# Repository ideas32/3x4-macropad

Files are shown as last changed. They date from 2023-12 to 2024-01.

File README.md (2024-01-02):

# 3x4 macropad
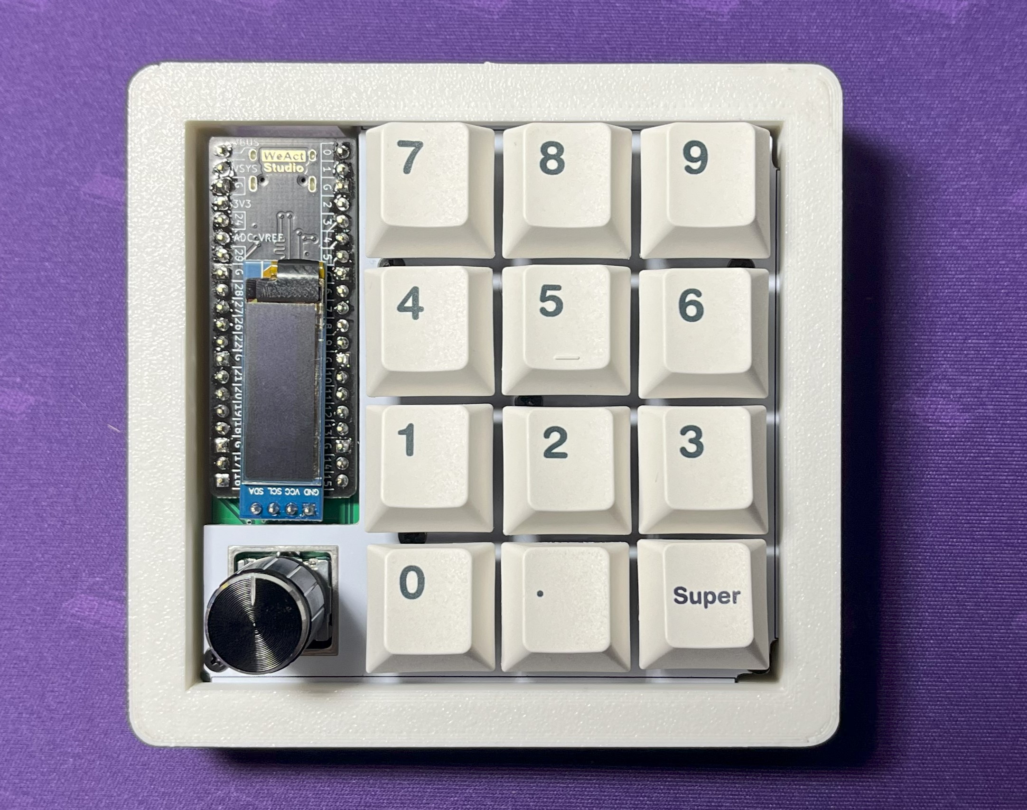
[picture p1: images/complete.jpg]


A 3x4 hotswap macropad with per-key rgb, rgb underglow, an oled, and an encoder. Uses the Weact Pi Pico as the microcontroller.
## Features:
- 3x4 array of south-facing MX switches
- hotswap (kailh sockets or equivilant)
- gasket mount
- support for a single 128x32 OLED placed above the microcontroller
- support for a single Alps EC11 rotary encoder
- support for addresable per-key rgb (SK6812 MINI-E) 
- support for addresable rgb underglow (WS2812b)
- through-hole and surface mount diode compatible
- uses a WeAct Studio Pi Pico as the microcontroller 
## Parts List
- 1x Weact Pi Pico
- 1x Alps EC11 encoder
- 12x Kailh or equivilant hotswap sockets
- 14x 1n4148 signal diodes (I prefer through-hole for ease of soldering, but surface mount is also supported)
- 16x M2x3mm screws, preferably with a thin head
- 6x M2x4mm female-female standoffs
- 12x MX-style switches
- 12x MX-style keycaps
- 1x Alps EC11 encoder knob
- 1x PCB, 1.6mm thick
- 1x Plate, 1.6mm thick (I recommend FR4)
- 1x 3d printed Case Top 
- 1x 3d printed Case Bottom 
- 1x 4-6mm thick sheet of foam to make gaskets OR gaskets around 4mm wide by 80mm long by 4-6mm high
- 12x SK6812 Mini-E LEDs (optional)
- 4x WS2812B LEDs (optional)
- 2x 4k7 resistors (only if using OLED)
- 1x SSD1306 128x32 OLED (optional)

Total cost excluding filament, switches, and keycaps when sourced from AliExpress and JLCPCB: ~$50
## Tools Required
- Screwdriver
- Soldering iron, solder, and basic soldering skills (SMD and THT)
- Flush cutters
- QMK source code and knowlege of how to build from source
- 3D printer and filament
# [Build Guide](Build%20Guide.md)

# Notes on the case:
- All filaments except PETG should be ok. I recommend staying away from PETG unless small holes turn out dimensionally accurate (which was not true in my case).
- Bottom case should be printed with transparent filament if using underglow
- Bottom case does require supports, top case does not
- Top case should be printed upside down
- Top case uses 4 M2 heatset inserts
- Assembled using 4x M2x3mm

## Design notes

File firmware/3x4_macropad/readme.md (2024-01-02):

# 3x4_macropad

3x4_macropad

A 3x4 macropad with encoder and 128x64 oled support. Uses the WeAct Studio RP2040 Core Board (WeAct Studio Pi Pico) as the microcontroller. 
* Keyboard Maintainer: [Kean Li](https://github.com/ideas32)
* Hardware Supported: WeAct RP2040 Coreboard (WeAct Pi Pico)
* Hardware Availability: *Links to where you can find this hardware*

Make example for this keyboard (after setting up your build environment):

    make 3x4_macropad:default

Flashing example for this keyboard:

    make 3x4_macropad:default:flash

See the [build environment setup](https://docs.qmk.fm/#/getting_started_build_tools) and the [make instructions](https://docs.qmk.fm/#/getting_started_make_guide) for more information. Brand new to QMK? Start with our [Complete Newbs Guide](https://docs.qmk.fm/#/newbs).

## Bootloader

Enter the bootloader in 3 ways:

* **Bootmagic reset**: Hold down the top-left key and plug in the keyboard
* **Physical reset button**: Press the button on the Pi Pico labeled "BOOTSEL" while plugging the keyboard in
* **Keycode in layout**: Press the key mapped to `QK_BOOT` if it is available

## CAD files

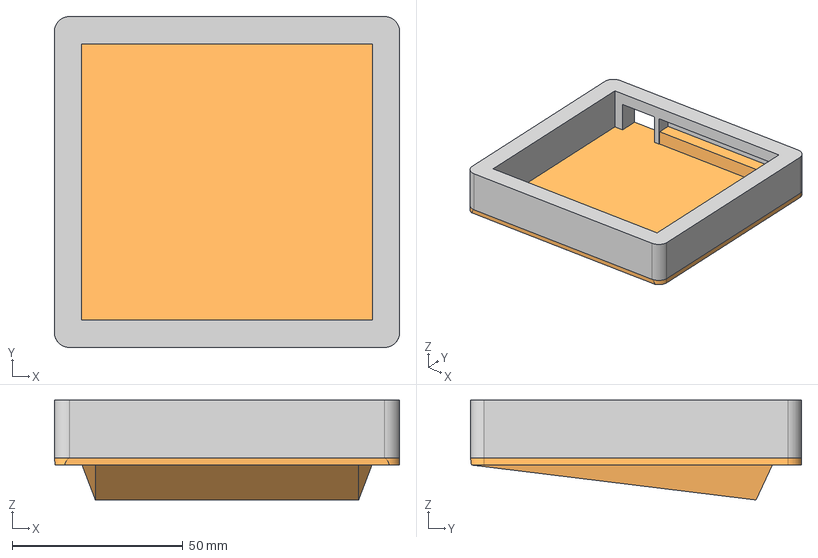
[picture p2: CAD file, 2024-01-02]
Case/Case.step
101.1 x 96.9 x 29.3 mm

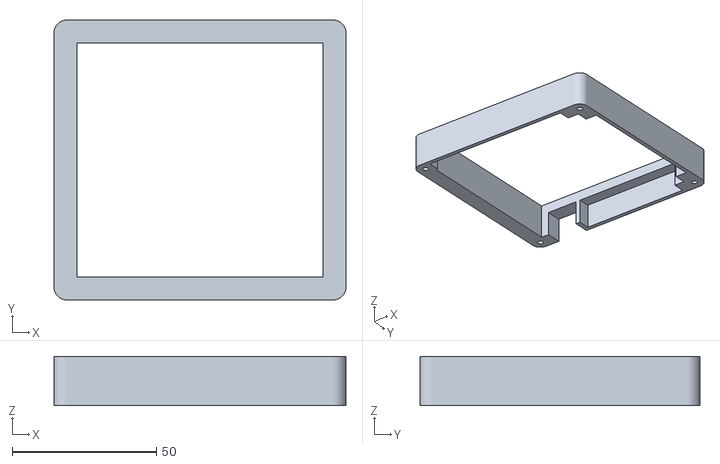
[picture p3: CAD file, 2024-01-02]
Case/Top Case.stl
101.1 x 96.9 x 17.0

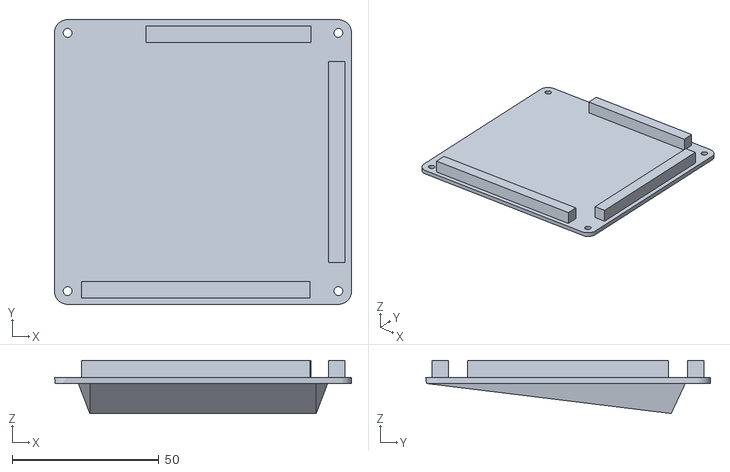
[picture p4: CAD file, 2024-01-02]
Case/Bottom Case.stl
101.1 x 96.9 x 18.1

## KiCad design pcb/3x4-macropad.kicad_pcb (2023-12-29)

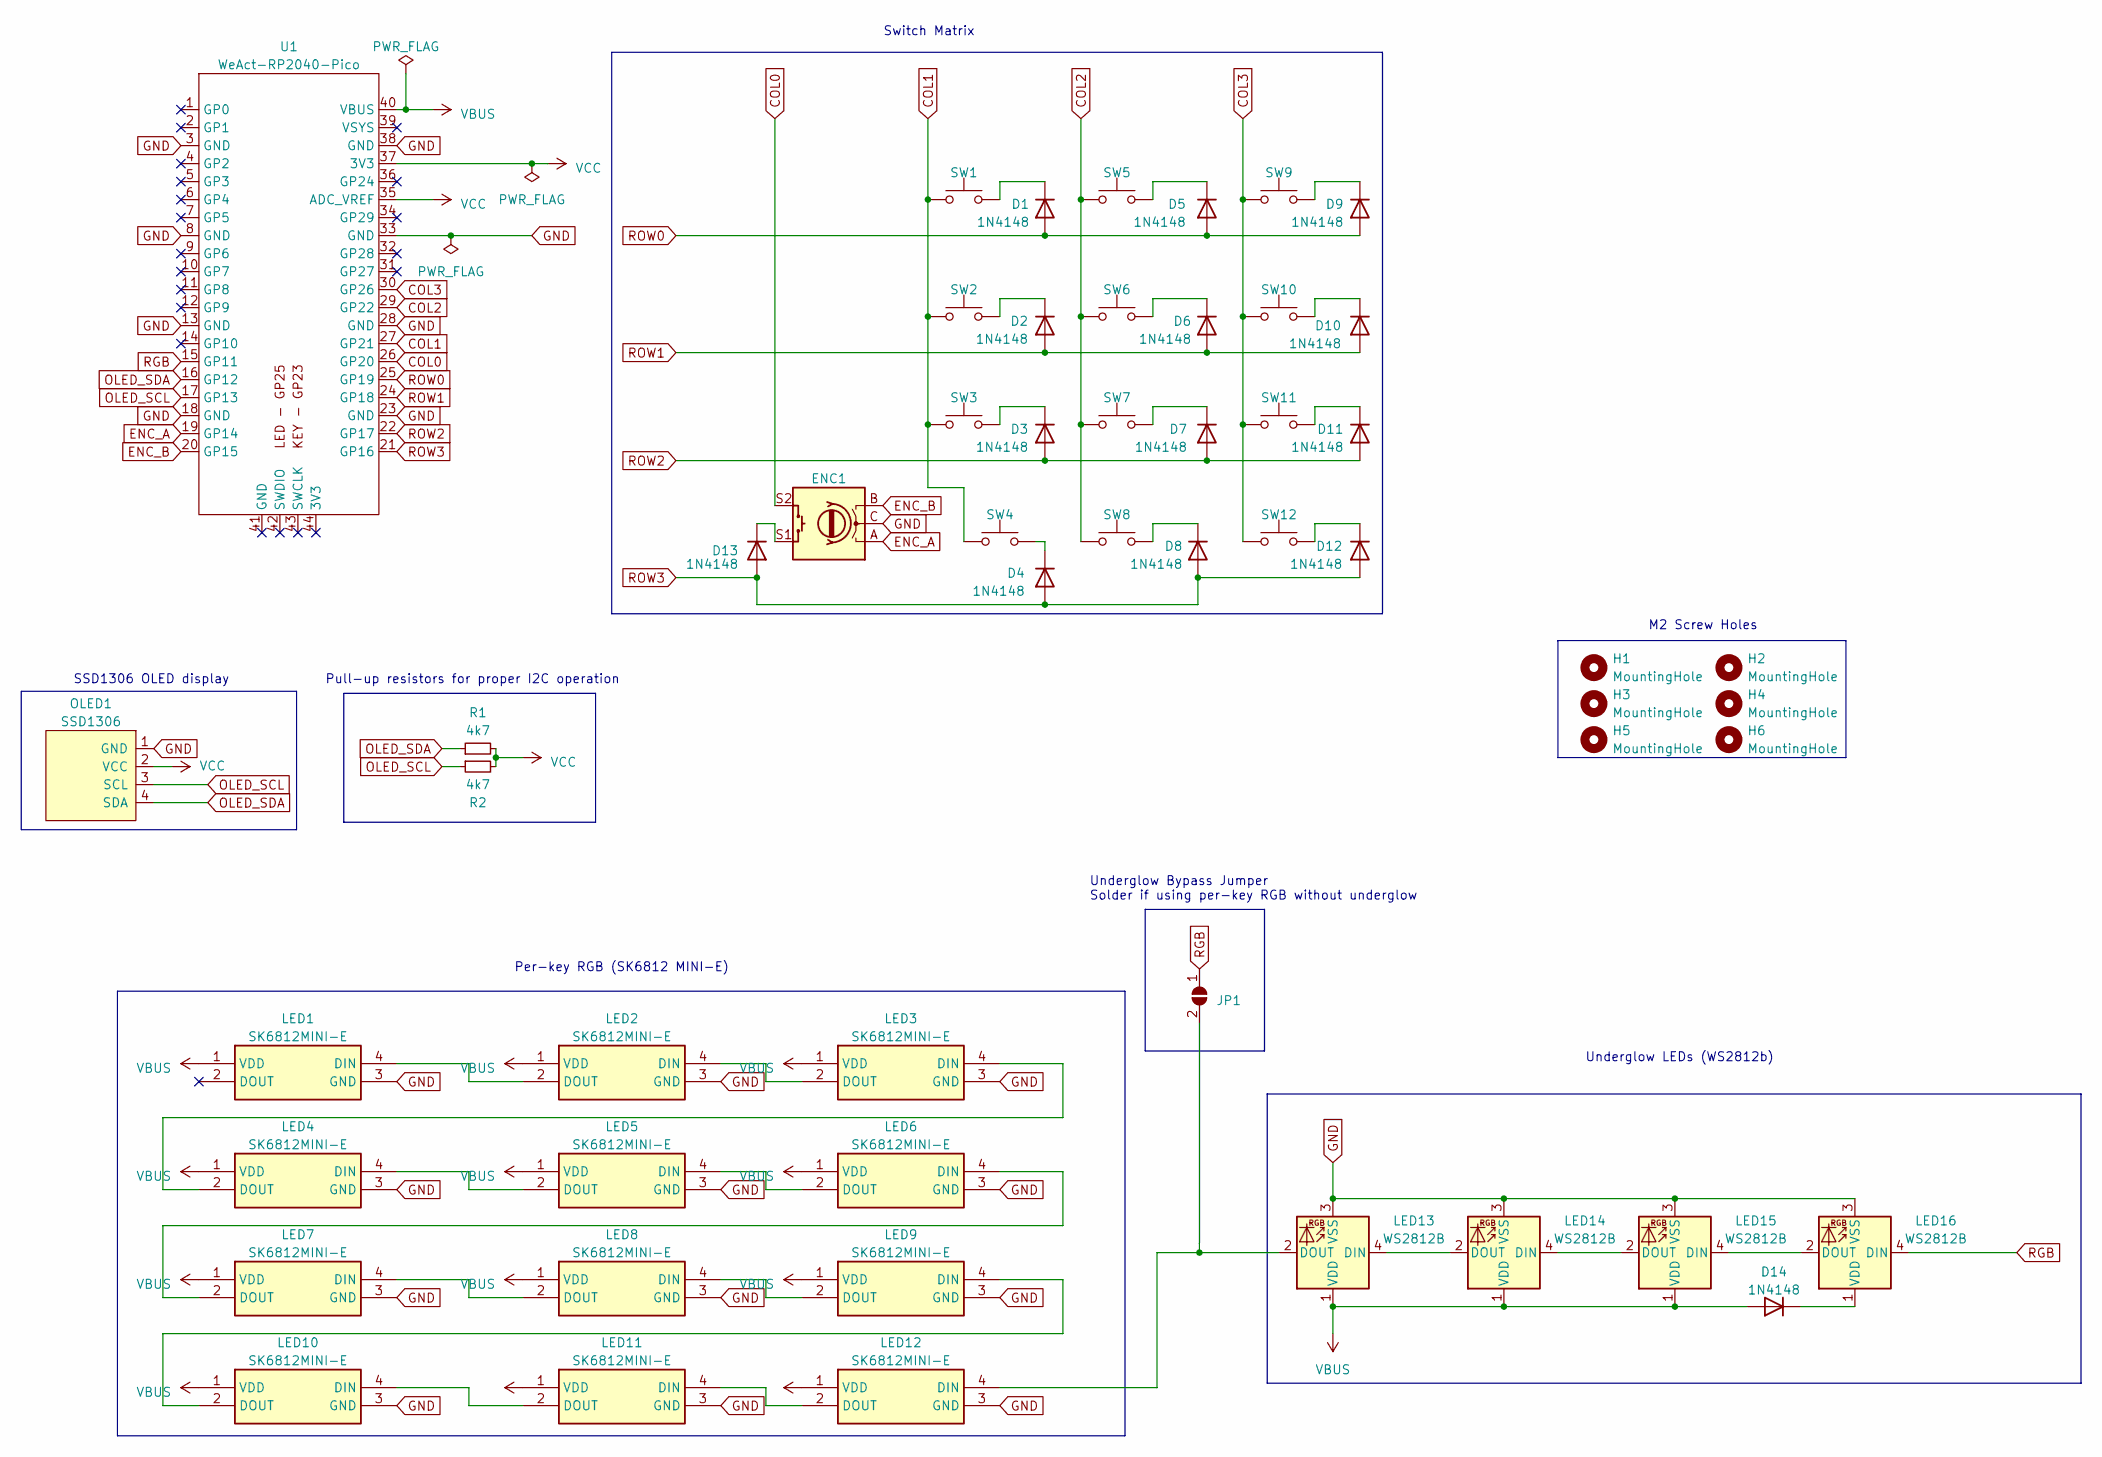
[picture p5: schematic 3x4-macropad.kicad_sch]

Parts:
D1, D2, D3, D4, D5, D6, D7, D8, D9, D10, D11, D12, D13, D14: 1N4148; Diode-Hybrid-Back
ENC1: RotaryEncoder_Switch; RotaryEncoder_Alps_EC11E-Switch_Vertical_H20mm
H1, H2, H3, H4, H5, H6: MountingHole; MountingHole_2.2mm_M2_DIN965_Pad_TopBottom
JP1: SolderJumper_2_Open; SolderJumper-2_P1.3mm_Open_RoundedPad1.0x1.5mm
LED1, LED2, LED3, LED4, LED5, LED6, LED7, LED8, LED9, LED10, LED11, LED12: SK6812MINI-E; SK6812-MINI-E; Manufacturer_Part_Number SK6812MINI-E
LED13, LED14, LED15, LED16: WS2812B
OLED1: SSD1306; I2C_Breakout
R1, R2: 4k7; Resistor-Hybrid
SW1, SW2, SW3, SW4, SW5, SW6, SW7, SW8, SW9, SW10, SW11, SW12: SW_Push; MX-Hotswap-1U
U1: WeAct-RP2040-Pico

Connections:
COL0: ENC1.S2, U1.26 (GP20)
COL1: SW1.1, SW2.1, SW3.1, SW4.1, U1.27 (GP21)
COL2: SW5.1, SW6.1, SW7.1, SW8.1, U1.29 (GP22)
COL3: SW9.1, SW10.1, SW11.1, SW12.1, U1.30 (GP26)
ENC_A: ENC1.A, U1.19 (GP14)
ENC_B: ENC1.B, U1.20 (GP15)
GND: ENC1.C, LED1.3 (GND), LED2.3 (GND), LED3.3 (GND), LED4.3 (GND), LED5.3 (GND), LED6.3 (GND), LED7.3 (GND), LED8.3 (GND), LED9.3 (GND), LED10.3 (GND), LED11.3 (GND), LED12.3 (GND), LED13.3 (VSS), LED14.3 (VSS), LED15.3 (VSS), LED16.3 (VSS), OLED1.1 (GND), U1.3 (GND), U1.8 (GND), U1.13 (GND), U1.18 (GND), U1.23 (GND), U1.28 (GND), U1.33 (GND), U1.38 (GND)
unnamed: D1.1 (K), SW1.2
unnamed: D2.1 (K), SW2.2
unnamed: D3.1 (K), SW3.2
unnamed: D4.1 (K), SW4.2
unnamed: D5.1 (K), SW5.2
unnamed: D6.1 (K), SW6.2
unnamed: D7.1 (K), SW7.2
unnamed: D8.1 (K), SW8.2
unnamed: D9.1 (K), SW9.2
unnamed: D10.1 (K), SW10.2
unnamed: D11.1 (K), SW11.2
unnamed: D12.1 (K), SW12.2
unnamed: D13.1 (K), ENC1.S1
unnamed: D14.1 (K), LED16.1 (VDD)
unnamed: JP1.2 (B), LED12.4 (DIN), LED13.2 (DOUT)
unnamed: LED1.4 (DIN), LED2.2 (DOUT)
unnamed: LED2.4 (DIN), LED3.2 (DOUT)
unnamed: LED3.4 (DIN), LED4.2 (DOUT)
unnamed: LED4.4 (DIN), LED5.2 (DOUT)
unnamed: LED5.4 (DIN), LED6.2 (DOUT)
unnamed: LED6.4 (DIN), LED7.2 (DOUT)
unnamed: LED7.4 (DIN), LED8.2 (DOUT)
unnamed: LED8.4 (DIN), LED9.2 (DOUT)
unnamed: LED10.4 (DIN), LED11.2 (DOUT)
unnamed: LED9.4 (DIN), LED10.2 (DOUT)
unnamed: LED11.4 (DIN), LED12.2 (DOUT)
unnamed: LED13.4 (DIN), LED14.2 (DOUT)
unnamed: LED14.4 (DIN), LED15.2 (DOUT)
unnamed: LED15.4 (DIN), LED16.2 (DOUT)
OLED_SCL: OLED1.3 (SCL), R2.1, U1.17 (GP13)
OLED_SDA: OLED1.4 (SDA), R1.1, U1.16 (GP12)
RGB: JP1.1 (A), LED16.4 (DIN), U1.15 (GP11)
ROW0: D1.2 (A), D5.2 (A), D9.2 (A), U1.25 (GP19)
ROW1: D2.2 (A), D6.2 (A), D10.2 (A), U1.24 (GP18)
ROW2: D3.2 (A), D7.2 (A), D11.2 (A), U1.22 (GP17)
ROW3: D4.2 (A), D8.2 (A), D12.2 (A), D13.2 (A), U1.21 (GP16)
VBUS: D14.2 (A), LED1.1 (VDD), LED2.1 (VDD), LED3.1 (VDD), LED4.1 (VDD), LED5.1 (VDD), LED6.1 (VDD), LED7.1 (VDD), LED8.1 (VDD), LED9.1 (VDD), LED10.1 (VDD), LED11.1 (VDD), LED12.1 (VDD), LED13.1 (VDD), LED14.1 (VDD), LED15.1 (VDD), U1.40 (VBUS)
VCC: OLED1.2 (VCC), R1.2, R2.2, U1.35 (ADC_VREF), U1.37 (3V3)

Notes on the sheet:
Switch Matrix
Per-key RGB (SK6812 MINI-E)
Underglow LEDs (WS2812b)
Pull-up resistors for proper I2C operation
M2 Screw Holes
Underglow Bypass Jumper Solder if using per-key RGB without underglow
SSD1306 OLED display

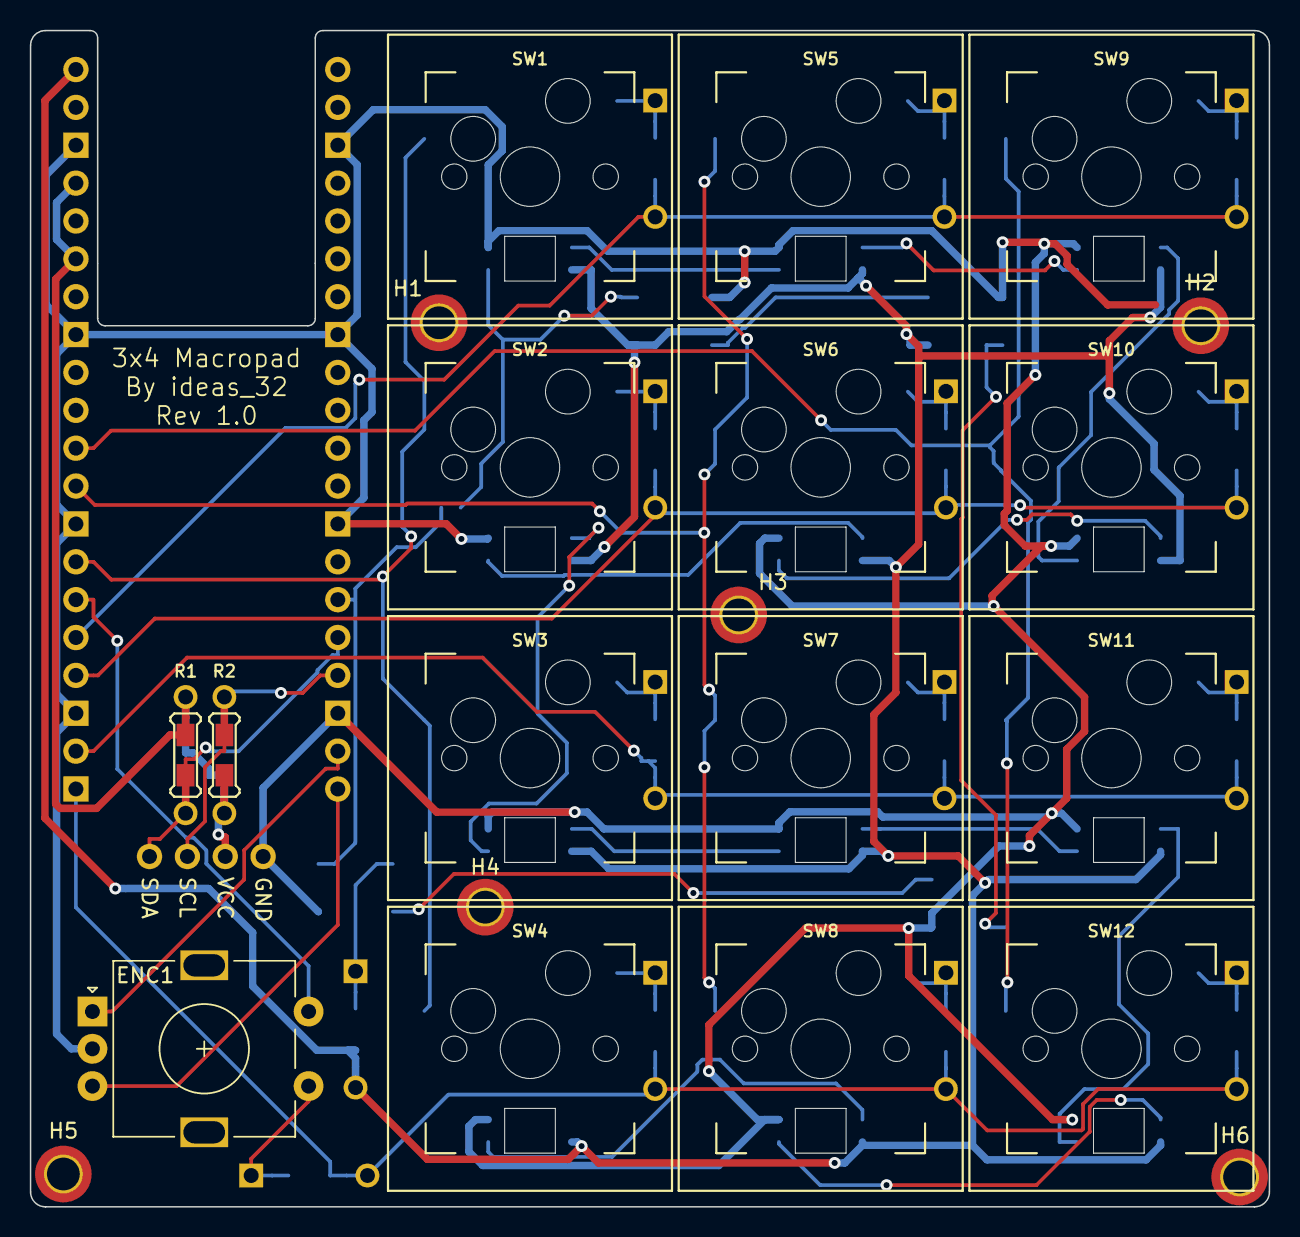
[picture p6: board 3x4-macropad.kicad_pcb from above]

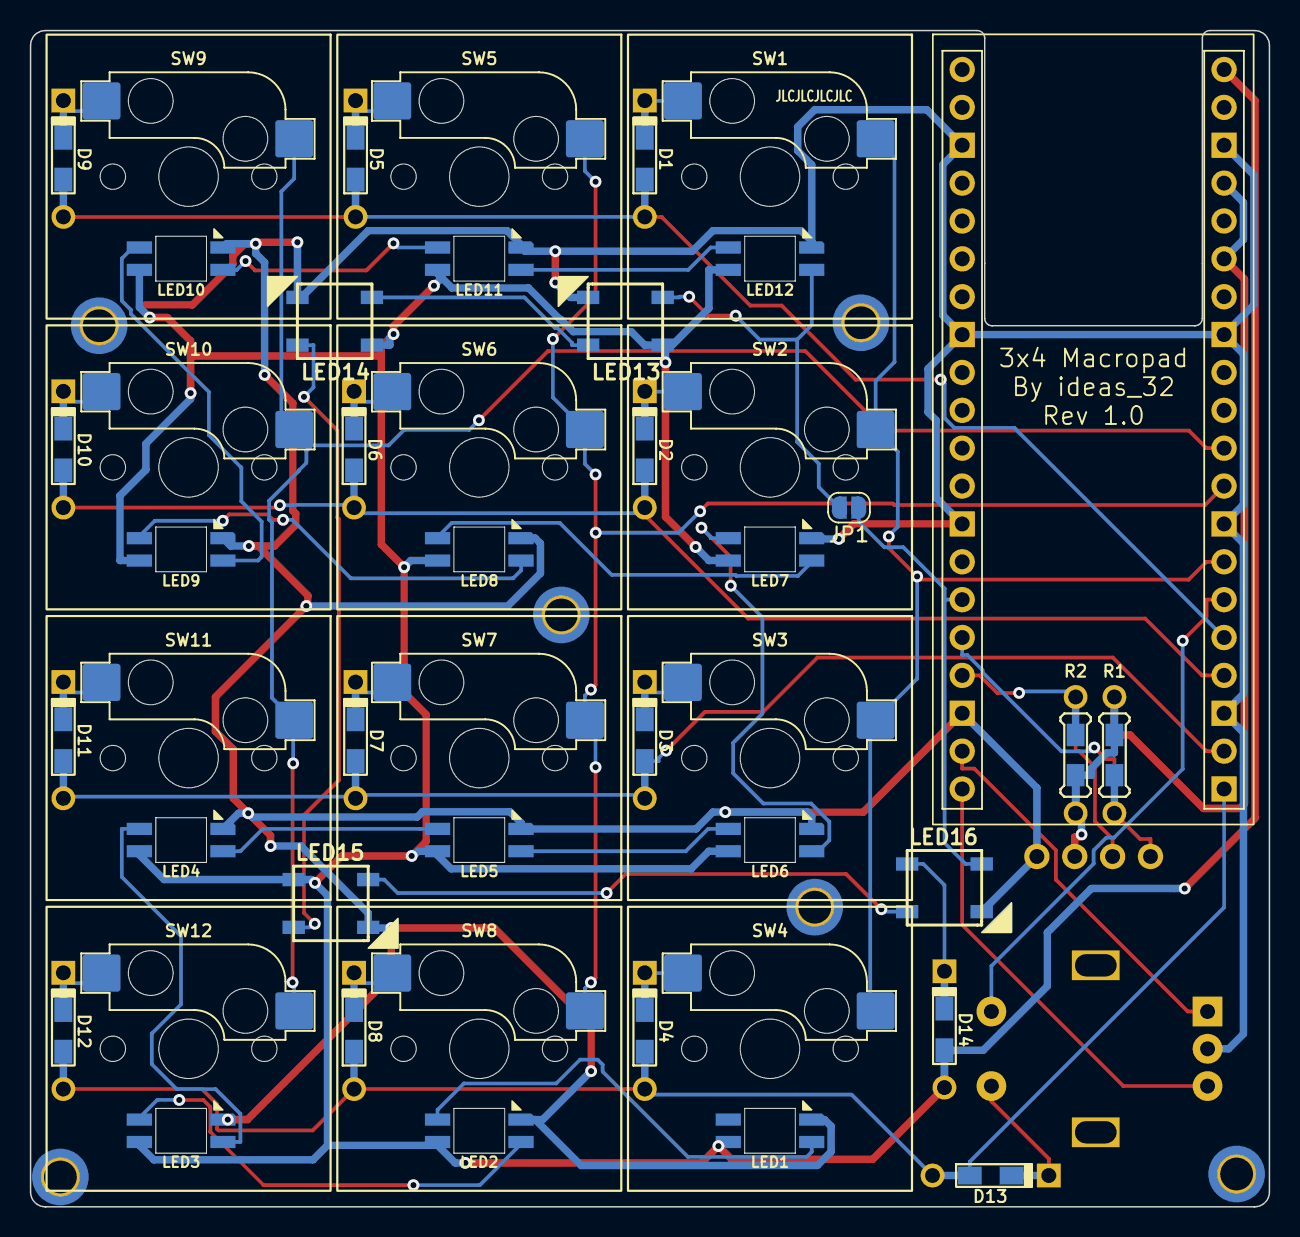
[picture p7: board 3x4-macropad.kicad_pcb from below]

Board: 2 copper layers, 83.1 x 78.9 mm, 54 parts (34 on the bottom side), 45 nets.

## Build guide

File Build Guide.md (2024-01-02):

# Build Guide
> While I did my best to write a build guide that a beginner would be able to understand, there are defininently better guides out there on how to build this style of Mechanical Keyboard. If at any point in this guide you are unsure on what to do or need more images/examples, [SplitKB](https://docs.splitkb.com/hc/en-us/sections/6269738440220-Aurora-Kyria-rev3-Build-Guide) has an extremly well written guide on how to build a kit similar to this. While not everything is the same and I recommend a different soldering order, I think SplitKB's guide is still applicable and will be quite helpful, especially if you are a beginner to soldering. 
## Materials


## Soldering the PCB
> Most images were taken with an older revision of the PCB. There are some minor differences compared to the current one.
### 1. Diodes:
Solder the diodes into the footprints marked with Dxx on the backside of the PCB. The side of the diode with the black stripe goes toward the side of the silkscreen with the thick white stripe. If unsure, check the pcb source files to make sure the direction/component is correct. Start off by bending the diode legs and inserting the diodes into the PCB. Cut off the diode legs from the top as close to flush to the pcb as possible when done.

#### Images:
Diode with legs bent\
\
Diode insertion into PCB\
\
Diode inserted into PCB\
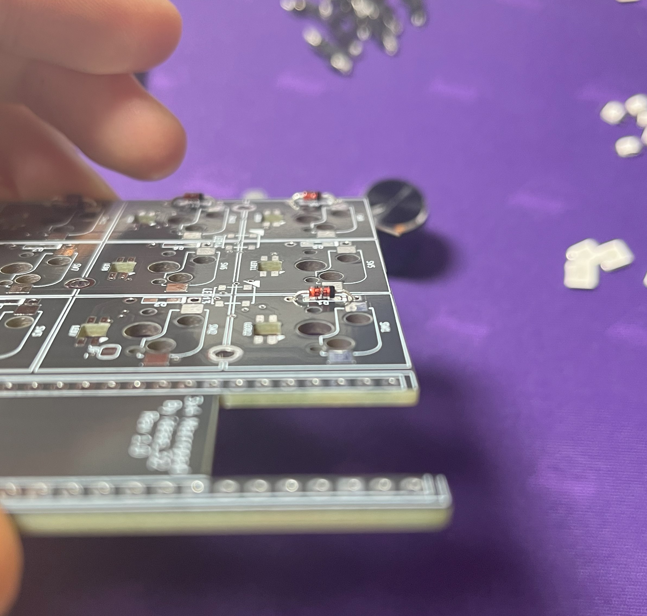
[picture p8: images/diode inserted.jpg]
\
Diode ready to solder\
\
Diodes soldered\
\
Diodes soldered and legs cut\


### 2. Resistors:
Solder resistors onto the pads labeled R1 and R2 on the back of the PCB. Polarity does not matter. Cut off these legs as well in the same manner as the diodes. 

#### Images: 
Resistors inserted into PCB:\
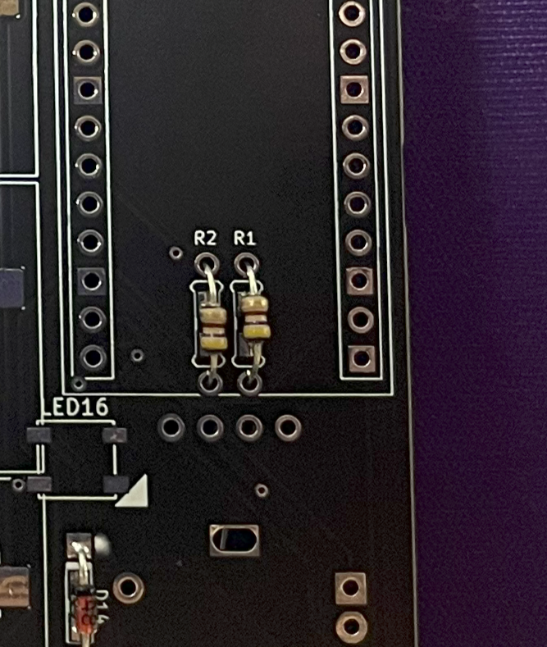
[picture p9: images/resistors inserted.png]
\
Resistors ready to solder:\
\
Resistors soldered:\
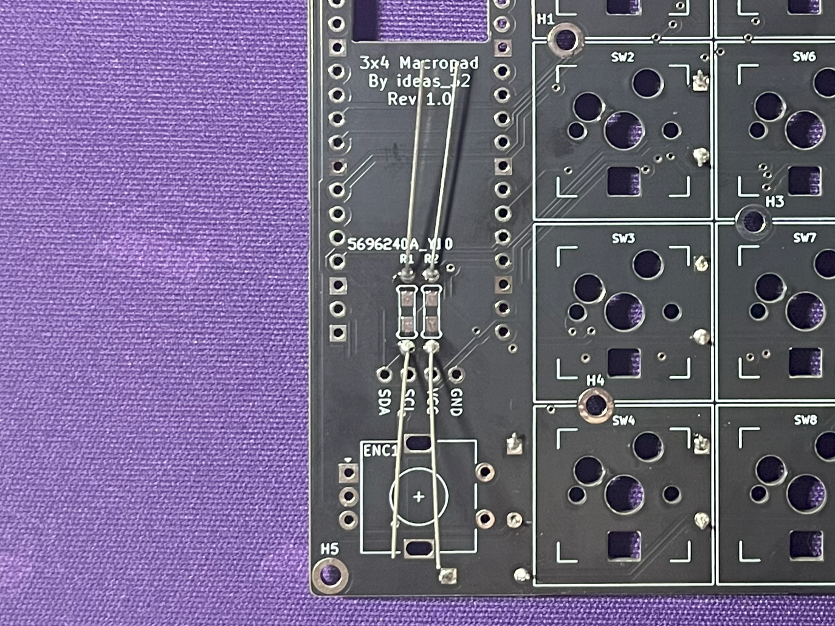
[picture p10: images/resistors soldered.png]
\
Resistors with legs cut:\


### 3. SK6812 MINI-E LEDs:
Skip this step if you aren't using per-key RGB. Splitkb's guide on this is extremely good and I don't think I could explain it better. I highly recommend following [it](https://docs.splitkb.com/hc/en-us/articles/6309893037852-Aurora-Build-Guide-4-Per-key-RGB-optional-) - it has great images and explanation. There are images of this keyboard particularly in this build guide if more examples are needed. 
#### Images:
SK6812 MINI-E LED:\
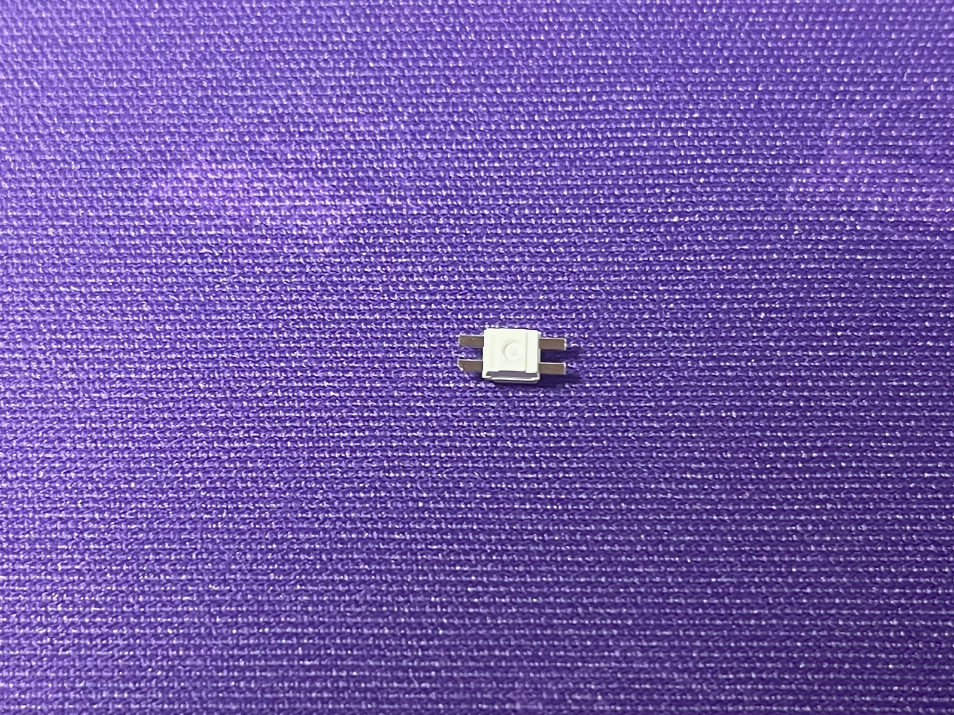
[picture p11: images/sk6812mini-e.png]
\
Tinned Pads:\
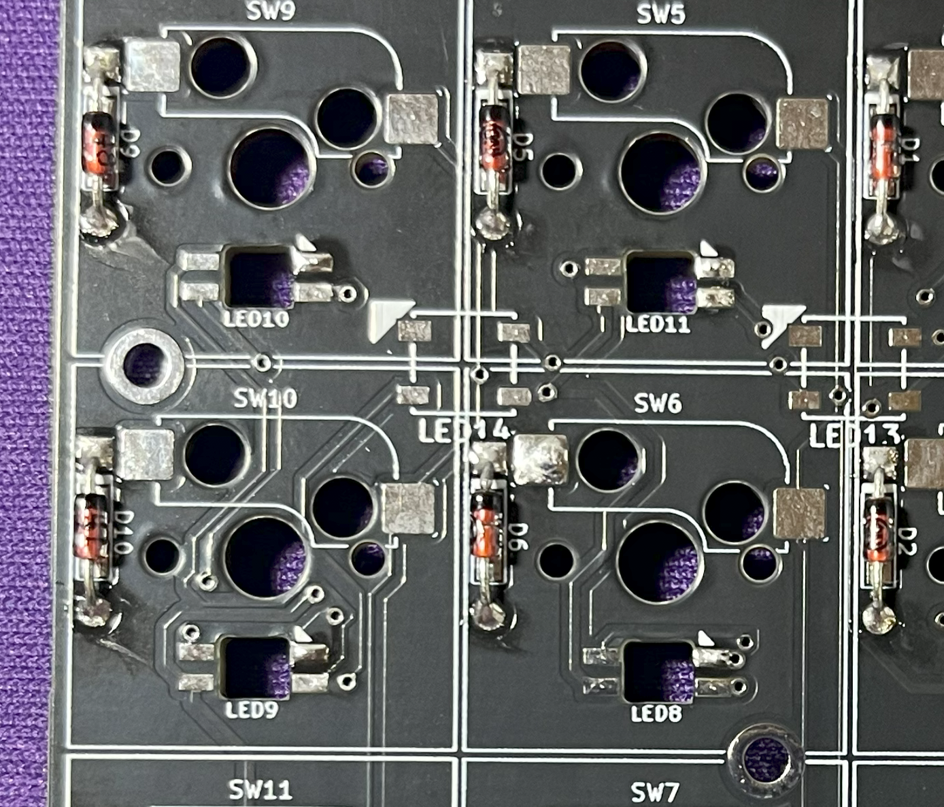
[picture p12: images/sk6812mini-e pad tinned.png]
\
LED oriented properly:\
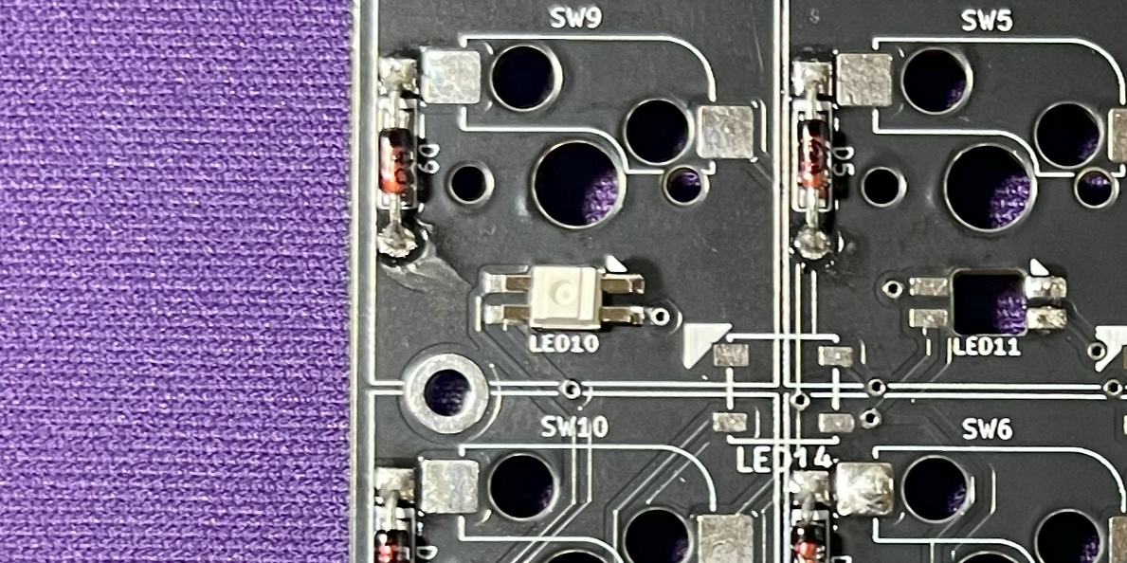
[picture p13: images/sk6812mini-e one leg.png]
\
LEDs soldered (frontside):\
\
LEDs soldered (Backside):\


### 4. WS2812B LEDs:
> If you are using per-key RGB without underglow, solder the jumper labeld JP1 on the backside of the PCB.

These are soldered face-up with the chamfered corner aligned with the triangle on the skilkscreen, with the same technique as the SK6812 MINI-E LEDs. See [this guide](https://docs.splitkb.com/hc/en-us/articles/6309982106012-Aurora-Build-Guide-5-RGB-Underglow-optional-).

#### Images:
LEDs soldered correctly:\


### 5. Hotswap Sockets:
Hotswap sockets: Solder the hotswap sockets to the PCB, with the same technique as the LEDs. Make sure that they are oriented correctly - the holes for the switches shouldn't be obstructed by the sockets. Follow [this guide](https://docs.splitkb.com/hc/en-us/articles/6310106113052-Aurora-Build-Guide-7-Switch-Sockets), but skip the part talking about encoders.

#### Images:
Tinning the pads:\
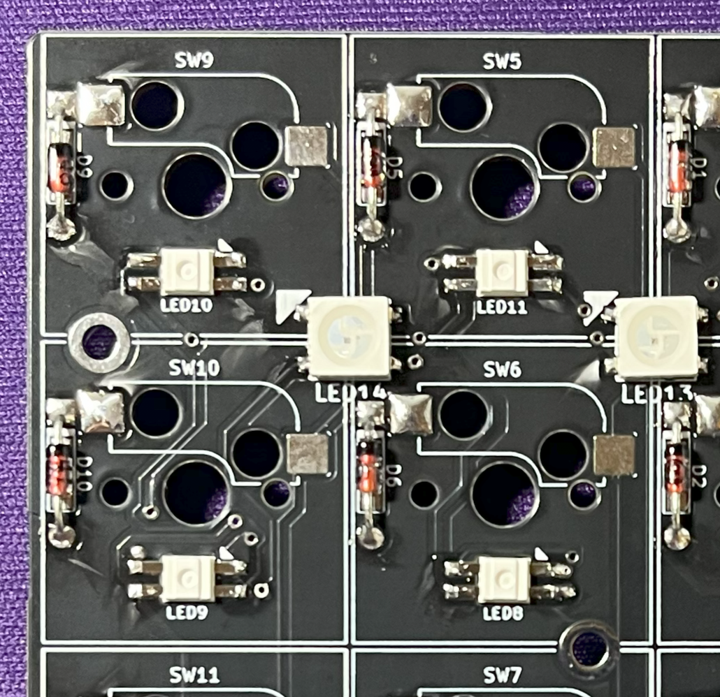
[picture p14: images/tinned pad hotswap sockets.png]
\
All Done, with the correct orientation:\


### 6. Flash Pi Pico with firmware
#### Prequisites:
QMK set up and ready to go. 

This keyboard's source code can be found in this repo in ```firmware/3x4_macropad/```. Copy and paste the entire folder, including the ```3x4_macropad``` part, into the keyboards folder in QMK. Compile the firmware using ```qmk compile -kb 3x4_macropad -km default```. This should generate a ```.uf2``` file that can now be flashed onto the Pi Pico. The flashing process for the RP2040, which is the microcontroller on the Pi Pico, is different from the usual STM32 or AVR processors. When put into flashing mode, which can be done by plugging the board in while holding the ```BOOTSEL``` button, the Pi appears as a USB drive. Flash the board by dragging the ```.uf2``` to the Pi in File Explorer/Finder/any file manager. The USB drive should dissapear and the pi should reboot itself as a keyboard after a couple of seconds. 

### 7. Pi Pico:
Solder the Pi Pico face-down on the topside of the PCB using the included headers. This means the usb-c port is in between the microcontroller's PCB and the keyboard's PCB, facing away from the encoder, and the golden "WeAct Studio" logo is face up. You should be able to access the reset button after soldering. Everything before this has been on the back side, so this is a good place to check your work. See [this guide](https://docs.splitkb.com/hc/en-us/articles/6331218321180-Aurora-Build-Guide-14b-Microcontroller-headers-).

### 8. Check your work:
Before continuing, check your soldering for any bridges or poor joints. The LEDs in particular are harder to solder properly, so don't be suprised if only 2 or 3 work first time. Because these LEDs work by sending signals down the LED chain, a single bad LED will stop everything downstream of it on the chain from functioning. The chain for the LEDs goes from LED16 -> LED1. If none of the LEDs are functioning and you are using only per-key RGB, make sure that the jumper JP1 is soldered. 

### 9. OLED:
Skip this step if you don't plan on using an OLED. Solder the included headers onto the OLED first. It doesn't really matter how straight they are at this point in time, but try to keep them somewhat aligned. Next, solder the OLED with headers to the PCB. The OLED should sit above the Pi Pico but not touch it. The first part of [this guide](https://docs.splitkb.com/hc/en-us/articles/6333686725532-Aurora-Build-Guide-17-OLED-Displays-optional-) covers this quite well.

### 10. Encoder:
Place the encoder on the top of the PCB and make sure it's flat and paralell to the surface of the PCB. I recommend soldering all 7 pins for maximum stability, which this board is designed for. Other kits may not be designed with soldering the big pins in mind, so make sure to check whether the slots for the big pins are plated. If they are, they are probably safe to solder. 

### 11. Check your work (again):
Double check to make sure all the keys and encoder work properly. Most of the times, problems are caused by bad solder joints and can be fixed by reflowing the joint in question. Splitkb's article on [troubleshooting](https://docs.splitkb.com/hc/en-us/categories/360002241599-Troubleshooting) has great tips if you're still having trouble. If everything is working, you're done with soldering! 

## TAKE A BREAK
Seriously. Soldering takes a while and this is a good point to get some water and snacks. I also recommend cleaning up your buildspace after this step. This is the point where you get out of the soldering step and start assembling the keyboard. However, don't put your soldering iron away yet because there are heat-set inserts that go into the 3d printed case that requires use of a soldering iron. 

## Case Prep
### Heat Set Inserts:
You need 4 inserts for the 4 holes of the top case. The inserts should sit slightly below the surface of the case. 

### Hole size check:
The bottom case's holes are a little finicky sometimes and may require enlarging. As long as the M2 screws can fit through easily, they should be fine.

## Plate
### Gaskets:
Attach the gaskets to the bottom of the plate on the protruding rectangles. Most gaskets come too long, and need to be cut to size. This doesn't have to be super accurate, and as long as the gasket is smaller than the plate it should be fine. The lengths of the gaskets are different for the 3 sides.

### Final Assembly
Using the M2x3mm and M2 standoffs, attach the plate to the PCB. Next, insert switches and place on keycaps. Finally, set the plate-pcb assembly on the bottom case, add the top case on top, and screw the cases together from the bottom with 4 M2x3mm screws.

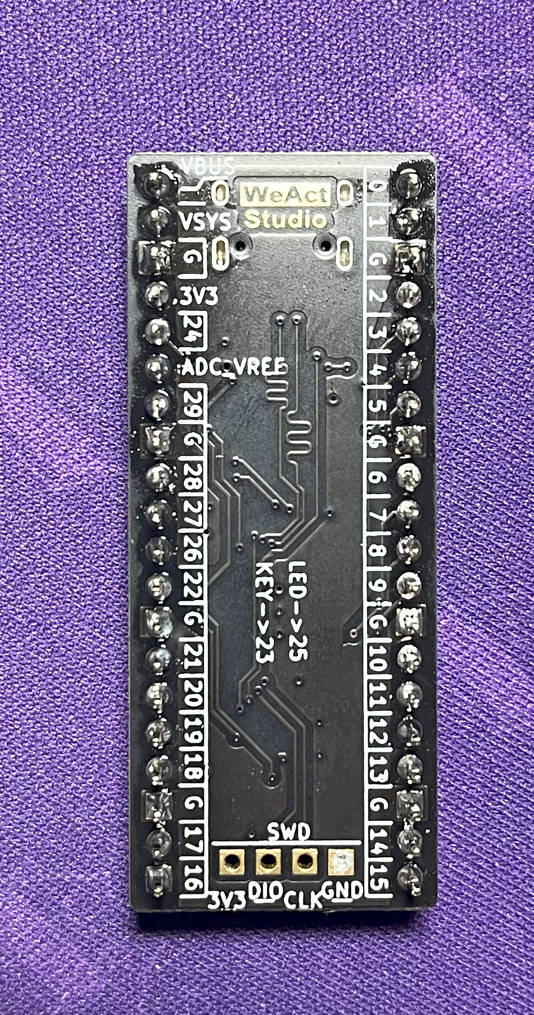
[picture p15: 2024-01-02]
images/pi pico soldered.png

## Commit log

2023-04-28 Initial Revision of case and pcb
    [3x4-macropad.kicad_pcb, 3x4-macropad.kicad_sch, Bottom.step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]
2023-04-28 Updated README.md and pcb with jlcpcb clearance requirements
    [3x4-macropad.kicad_pcb]
2023-05-03 changed silkscreen reference for the pi pico footprint
2023-05-04 Update README.md
    tested the case and wrote a to do list
2023-05-06 stuff
    - cleaned up routing
    - changed per-key rgb footprint
    - changed resistor footprint
    - changed diode footprint to actually support sod123
    - made power traces 0.5mm
    [3x4-macropad.kicad_pcb, 3x4-macropad.kicad_sch]
2023-05-16 Updates and QOL
    - changed revision silkscreen text
    - removed silkscreen on diode pads
    - updated readme.md
    - ready for rev 0.2
    [3x4-macropad.kicad_pcb]
2023-05-17 v0.2
    - bugfixes mostly
    - changed case to 4 part for cleaner print
    [Bottom.step, Parts - Base.obj, Parts - Hat.obj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]
2023-05-18 update gerbers
2023-05-22 flipped pi pico
    - boot is still accessible because of cutout in board
    [3x4-macropad.kicad_pcb]
2023-09-25 remove outdated case files
    [Parts - Base.obj, Parts - Hat.obj, Parts - Plate.obj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]
2023-09-26 V0.2 changed to gasket mount, added plate file, modified pcb to fix bugs
    [3x4-macropad.kicad_pcb, 3x4-macropad.kicad_sch]
2023-09-26 Initial release
    Combination of many bugfixes, finally commiting the plate, and updating the silkscreen text
    [3x4-macropad-B_Cu.gbr, 3x4-macropad-B_Mask.gbr, 3x4-macropad-B_Paste.gbr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]
2023-11-06 Fixed Bugs
    [3x4-macropad-B_Cu.gbr, 3x4-macropad-B_Mask.gbr, 3x4-macropad-B_Paste.gbr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]
2023-12-29 Removed zone that made ground pads hard to solder
    [3x4-macropad-B_Cu.gbr, 3x4-macropad-B_Mask.gbr, 3x4-macropad-B_Paste.gbr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]
2024-01-02 Documentation and plate update
    [plate-B_Cu.gbr, plate-B_Mask.gbr, plate-B_Paste.gbr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]
2024-01-02 Add case files
    [Bottom Case.stl, Case.step, Top Case.stl]
